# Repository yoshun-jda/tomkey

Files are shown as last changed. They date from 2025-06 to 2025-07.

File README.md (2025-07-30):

## description
- このキーボードは無線分割式 40% 19mm トラックボール内蔵のキーボードになります。
  tomkey keyboard

## ビルドガイド
- https://github.com/pukuhei/tomkey/blob/main/build_guide/build_guide.md
## スペック
- ファームウェア
  - ZMK を使用しています
  - ZMKStudio に対応しております
- ハードウェア
  - 43 キー
  - choc v1/v2、lofree 系列のスイッチが使用可能
  - 左手側が master,右手側が slave になります
  - 左手側に OLED 内蔵
  - トラックボールはケースごとマグネットで張り付いているので、脱着可能です
  - バッテリー対応 2 つ必要です
    - 横 25mm,縦 35mm,厚さ 5mm 以内のものを使用してください
    - 製作者はこちらを使用しています(https://amzn.asia/d/ebvtzoP)。250mAh で大体 1 週間は持ちます(1 日 5 時間使用くらい)
    - リチウムイオンバッテリーは十分注意して取り扱ってください(https://www.baj.or.jp/battery/safety/safety16.html)
    - 市販のバッテリーの極性が個体によって異なる例が確認されておりますので、極性には気をつけてご利用ください。tomkey では赤色を+極として作成しております

## 電源および充電について
※ご自身で購入したバッテリーによっては極性が逆になっている可能性がありますので、十分にご確認の上で接続をお願いいたします！(表記と端子が逆の事例もありました)
- スイッチを ON にしている状態で USB に接続することで充電されます。充電しながらの使用も可能です
- スイッチが OFF の状態で USB を接続すると USB からの給電で使用できますが、OFF の状態ではバッテリーに充電はされません
  - 安全上意図的にバッテリー ON 状態でないと充電されない仕様になっております
- バッテリー残量に関しては oled 上に表示されるようになっております
  - 上側が左手のバッテリー残量
  - 下側が右手のバッテリー残量

## oled の切り替えについて

- デフォルトでは us 配列の mac に適した配置になっております
- また oled も mac に併せてありますので、windows の方は以下の設定を n に指定することで表示が切り替わります
- config/boards/shields/tomkey/tomkey_L.conf
- `CONFIG_ZMK_DONGLE_DISPLAY_MAC_MODIFIERS=n`にする

## キーマップについて

- ZMKstudio にて確認・編集を行なってください

  - https://zmk.studio/

- ZMK keymap-editor も使用できます
  - マクロ設定などを使いたい場合はこちらを使うとべんりです
  - https://nickcoutsos.github.io/keymap-editor
  - ご使用の時は本リポジトリをフォークしてお使いください
    - ※フォークしてマクロ等にパスワードなどを設定する際はリポジトリが public になってしまい情報漏洩につながりますのでご注意ください

### レイヤーマップ

- レイヤー 0 がデフォルトです
- レイヤー 1 がオートマウスレイヤーです
  - トラックボール操作中に切り替わるレイヤーです(400ms でレイヤー０に切り替わります)
- レイヤー 2 がスクロールレイヤーです
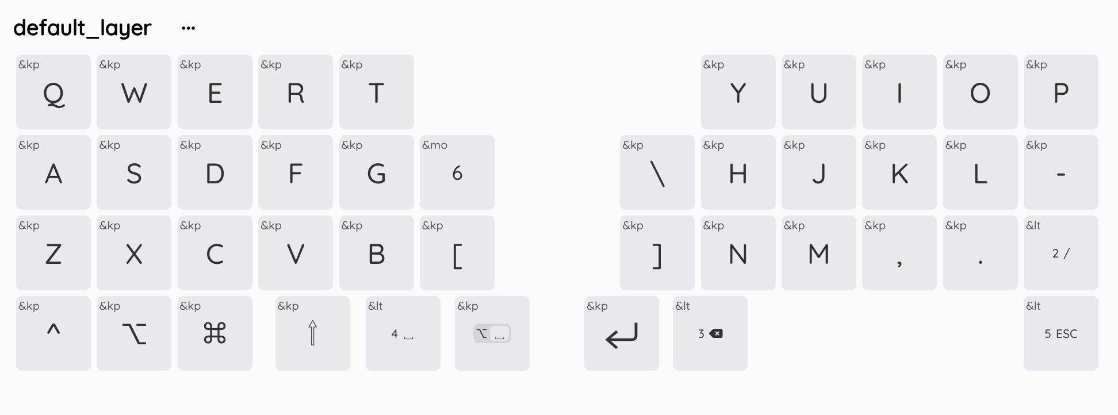
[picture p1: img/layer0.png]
tomkey layer0
  
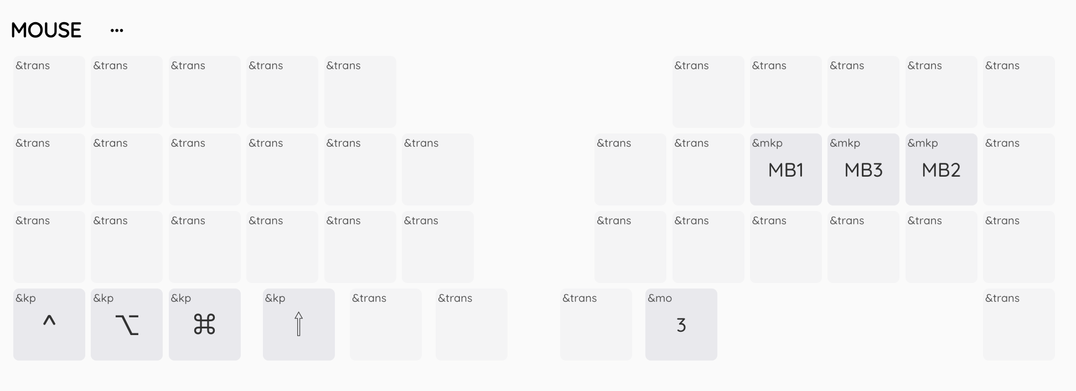
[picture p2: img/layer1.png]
tomkey layer1
  
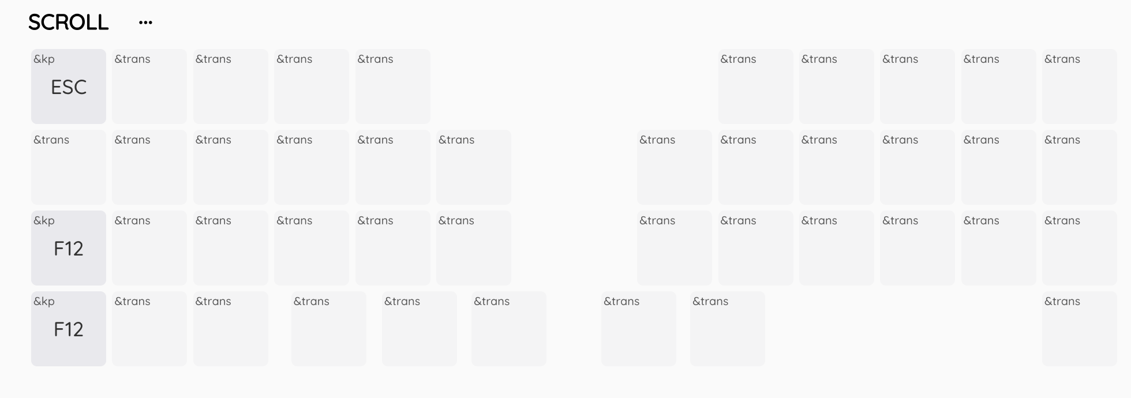
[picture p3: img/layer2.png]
tomkey layer2
  
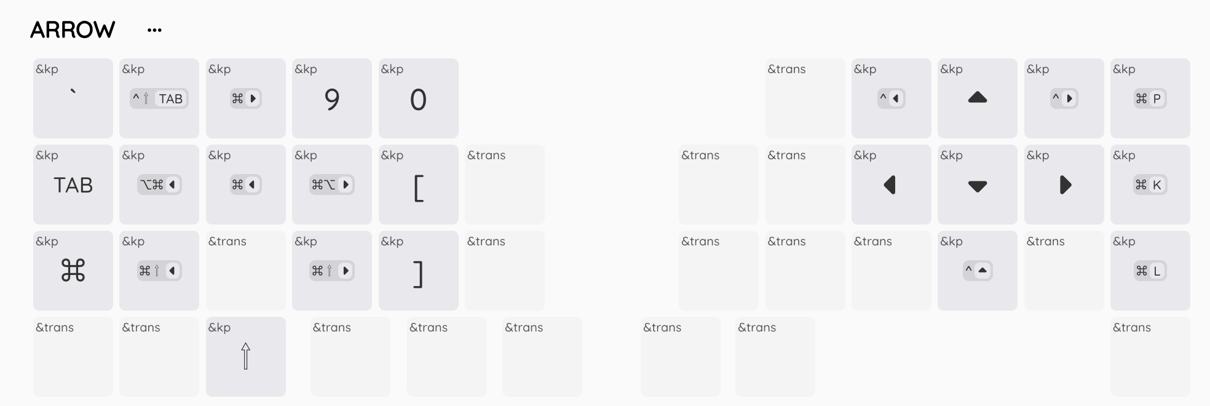
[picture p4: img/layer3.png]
tomkey layer3
  
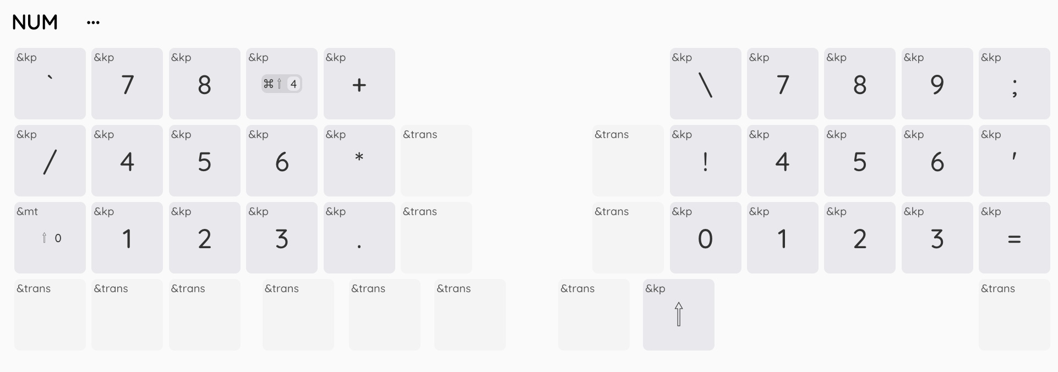
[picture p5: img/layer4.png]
tomkey layer4
  
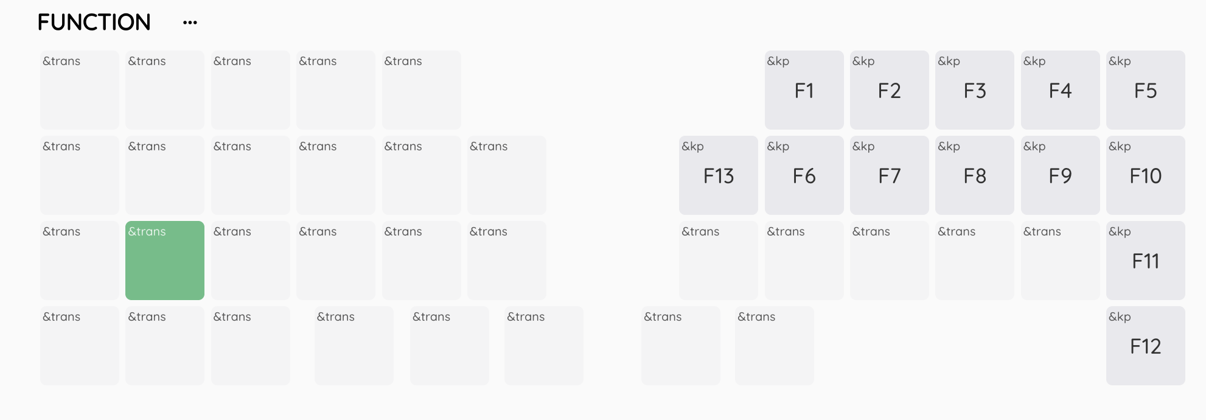
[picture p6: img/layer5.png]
tomkey layer5
  
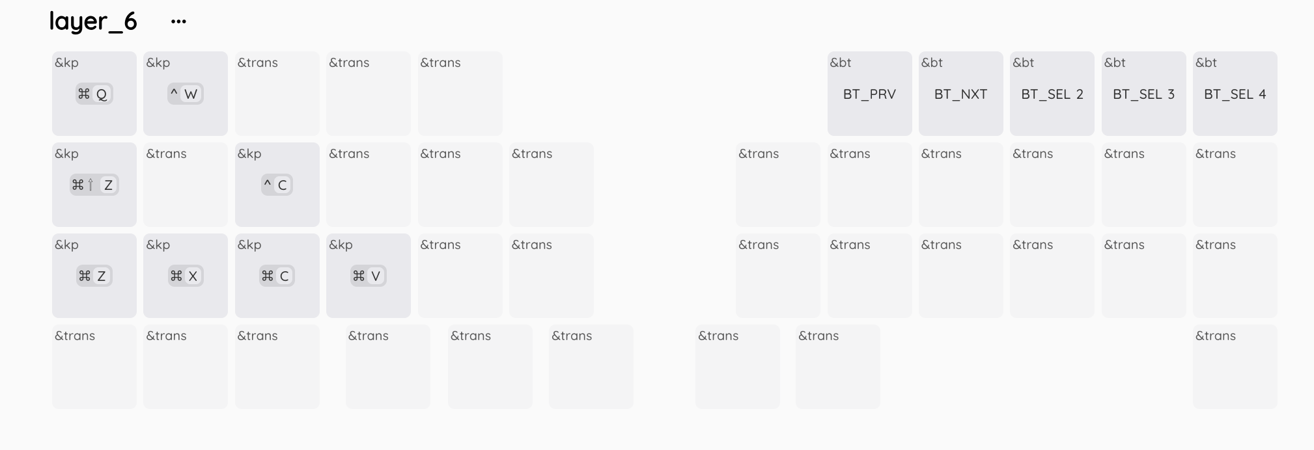
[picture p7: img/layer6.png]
tomkey layer6
  

## その他

不明な点がある場合は下記アカウントにご連絡ください
https://x.com/tomcat09131

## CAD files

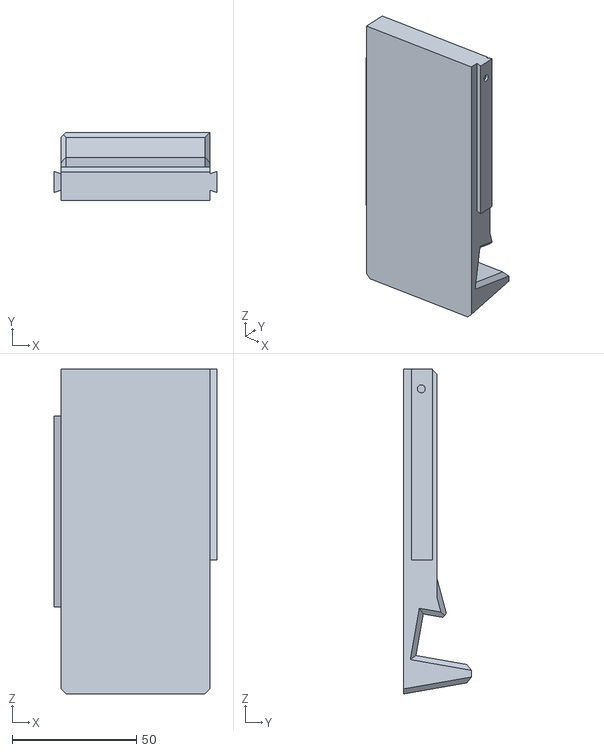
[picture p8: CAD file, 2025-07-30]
model/linker-stand.stl
65.6 x 27.5 x 131.0

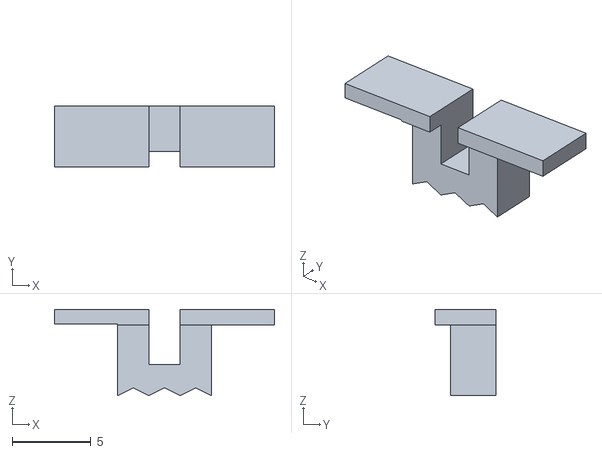
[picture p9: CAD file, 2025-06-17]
model/tomkey-r-sw.stl
14.0 x 3.90 x 5.50

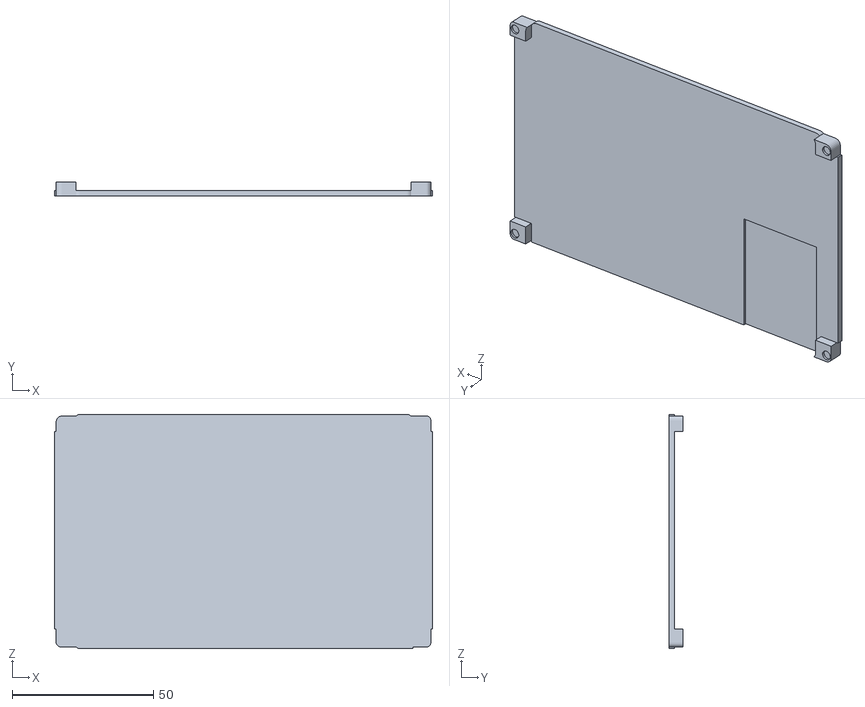
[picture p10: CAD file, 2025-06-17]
model/tomkey-r-bottom.stl
134.0 x 5.00 x 83.0

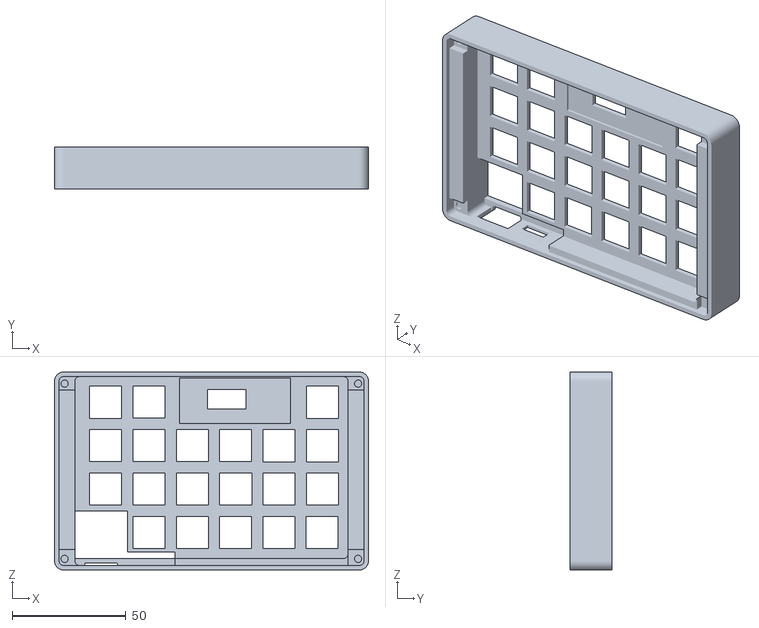
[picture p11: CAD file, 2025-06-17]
model/tomkey-r-body.stl
138.0 x 18.5 x 87.0

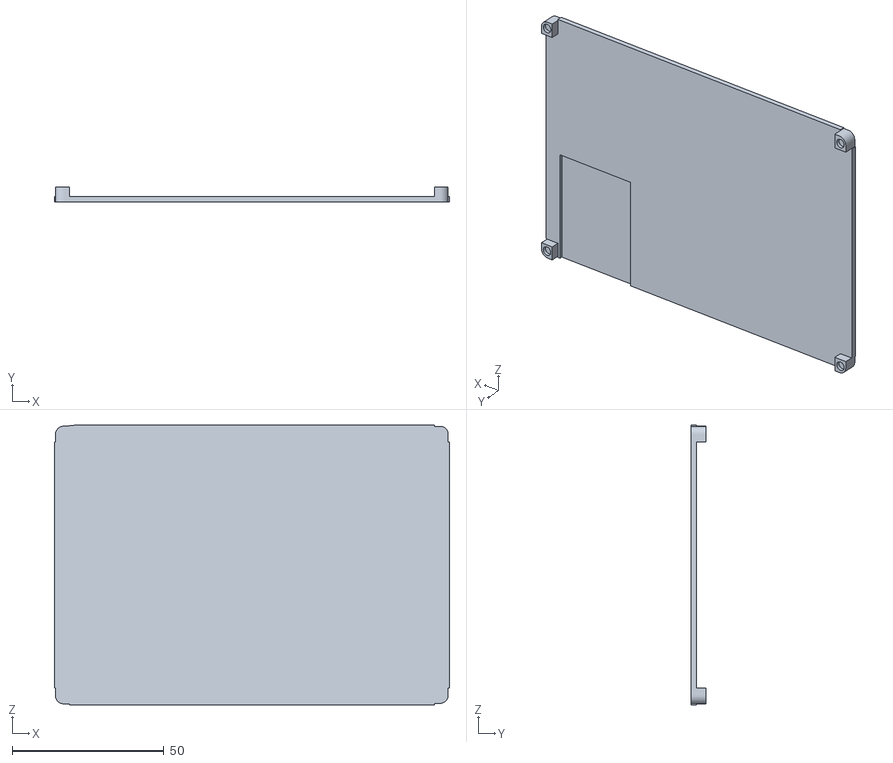
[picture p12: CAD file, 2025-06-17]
model/tomkey-l-bottom.stl
130.0 x 4.90 x 92.0

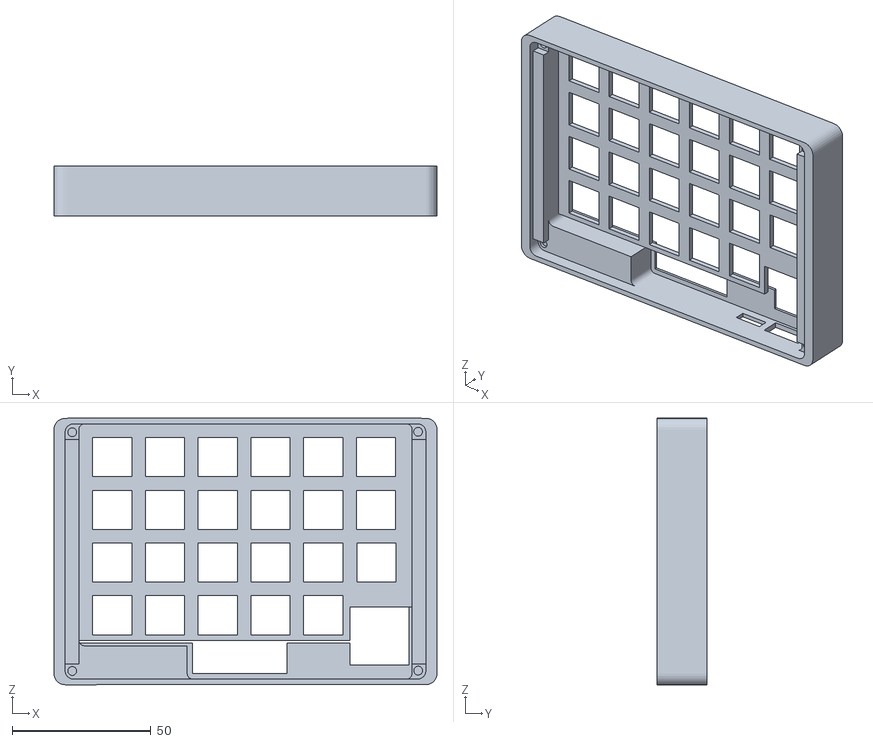
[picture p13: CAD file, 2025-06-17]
model/tomkey-l-body.stl
138.0 x 18.0 x 96.0

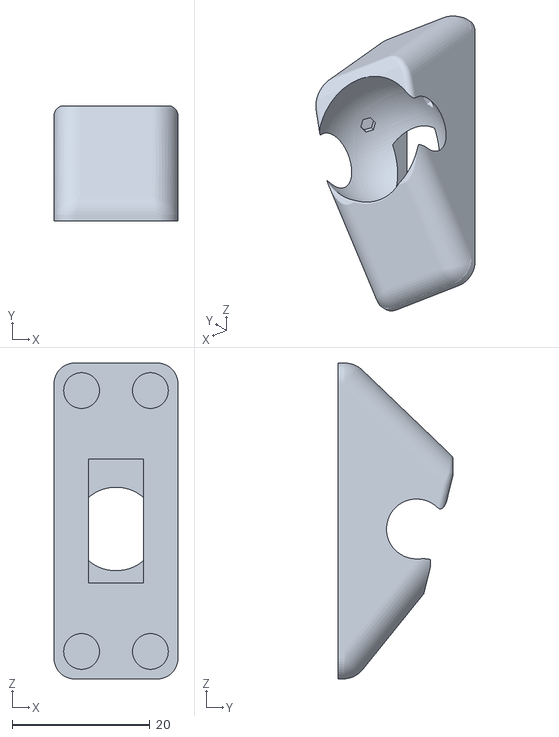
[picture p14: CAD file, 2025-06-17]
model/trabo.stl
18.0 x 16.8 x 45.9

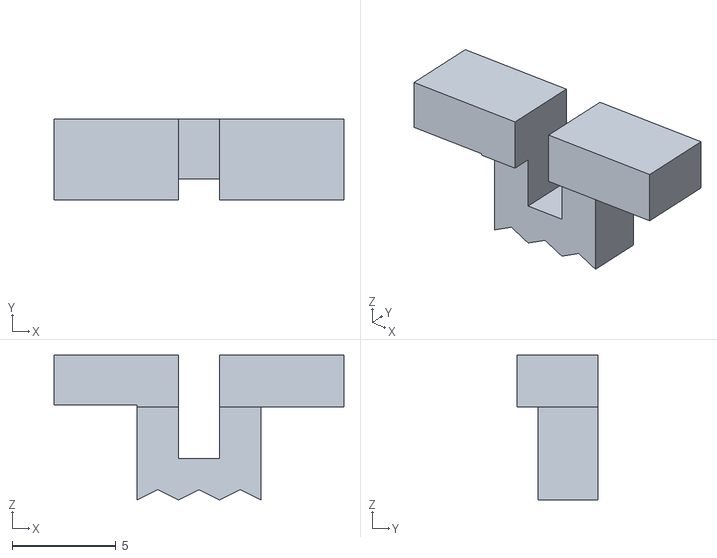
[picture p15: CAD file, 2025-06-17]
model/tomkey-l-sw.stl
14.0 x 3.90 x 7.00

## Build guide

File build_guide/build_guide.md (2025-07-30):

## マイコンカバーについて

- マイコンカバーは選択式のため、固定はしておりませんためそのままの状態だと外れることがあります
- 使用する場合は裏面に小さく両面テープなどをつけて固定しておつかください

## トラックボールセンサーについて

- トラックボールセンサーのレンズユニットが使っていると振動や摩耗などで浮いてくる場合があります。
- ウキがあるとトラックボールが正常に認識できませんので上から軽く押して止め直してください。必要に応じて接着剤などで固定をお願いします
  - 組み立て時点でウキがあるものは製作者側で接着固定している場合があります

## 電源スイッチカバーの取り付け

- 一応スイッチには上下で形状が異なります。通常の画像の向き(下側が平らで、上側が出っ張り)で取り付けます。もしスイッチが緩くてアソビが強い場合は上下逆にして取り付けてください
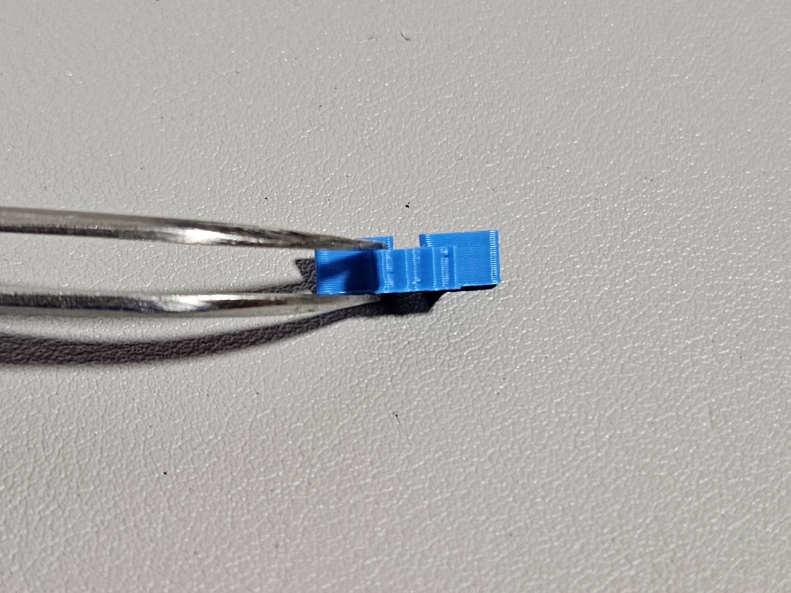
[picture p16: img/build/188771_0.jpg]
sw01
- 
- またスイッチは厚みがある方が左手側、薄い方が右手側のスイッチになります

## キースイッチの取り付け

- キースイッチを取り付ける際は、ケースを持ちながら基盤を後ろから支えて押し込んで挿入します
- 差し込みが甘いとキー入力ができませんので、しっかりと全部奥まで差し込まれていることを確認の上でご使用ください
- 差し込んでいるのにキースイッチが反応しない場合は、 スイッチのピンを曲げてしまっている可能性があるので取り付け直してください
- 最初に四隅から取り付けると安定して取り付けやすいです
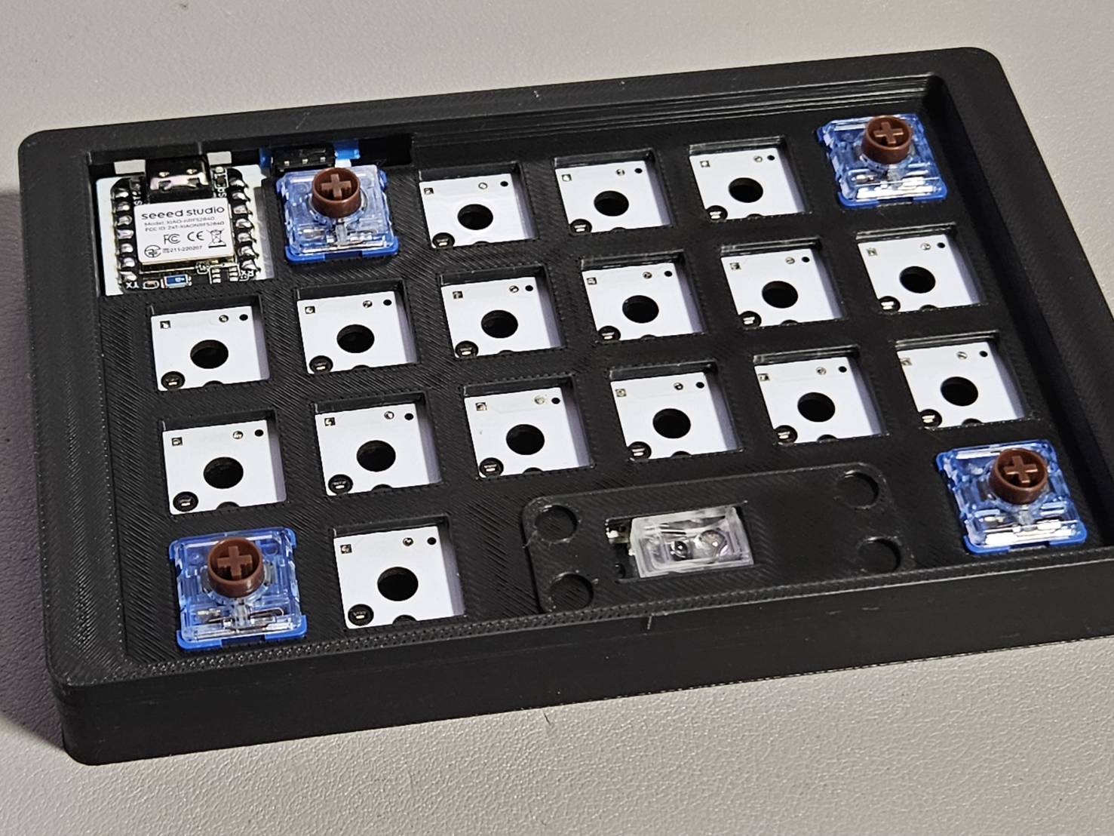
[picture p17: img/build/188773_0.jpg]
ksw01
- 
- 外す時はケース裏側から、スイッチのセンターを押し出すと簡単に外れます。硬い場合はピンセット裏側など固いもので押し込むとやりやすいです
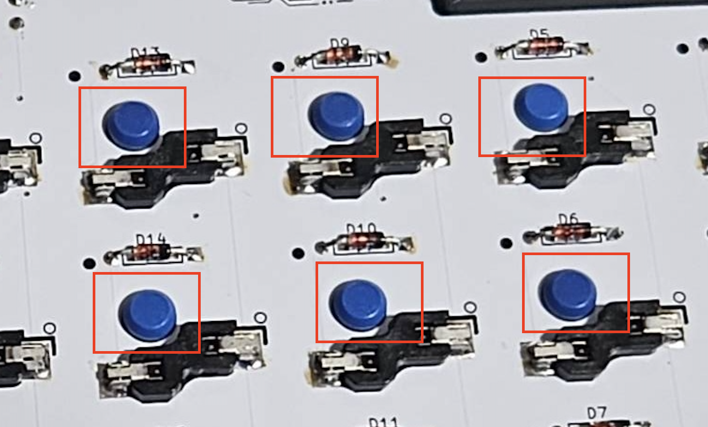
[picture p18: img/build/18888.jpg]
ksw02
- 

## バッテリーの接続

- マイコン部分の裏側にあらかじめ JST プラグ 1.25mm のメス端子を接続してありますので、裏面カバーを外してここにバッテリーを接続します
- 購入されるバッテリーによっては、+極と-極が逆に接続されている可能性があります。その状態で本体と接続しますとマイコンの破壊、バッテリーの発火の原因となりますので事前に確認を行なった上で取り付けをお願い致します
- tomkey では+極を赤色、GND を黒色で配線しております
- 基本的にご購入されたバッテリーは動作確認済品をおつけしております
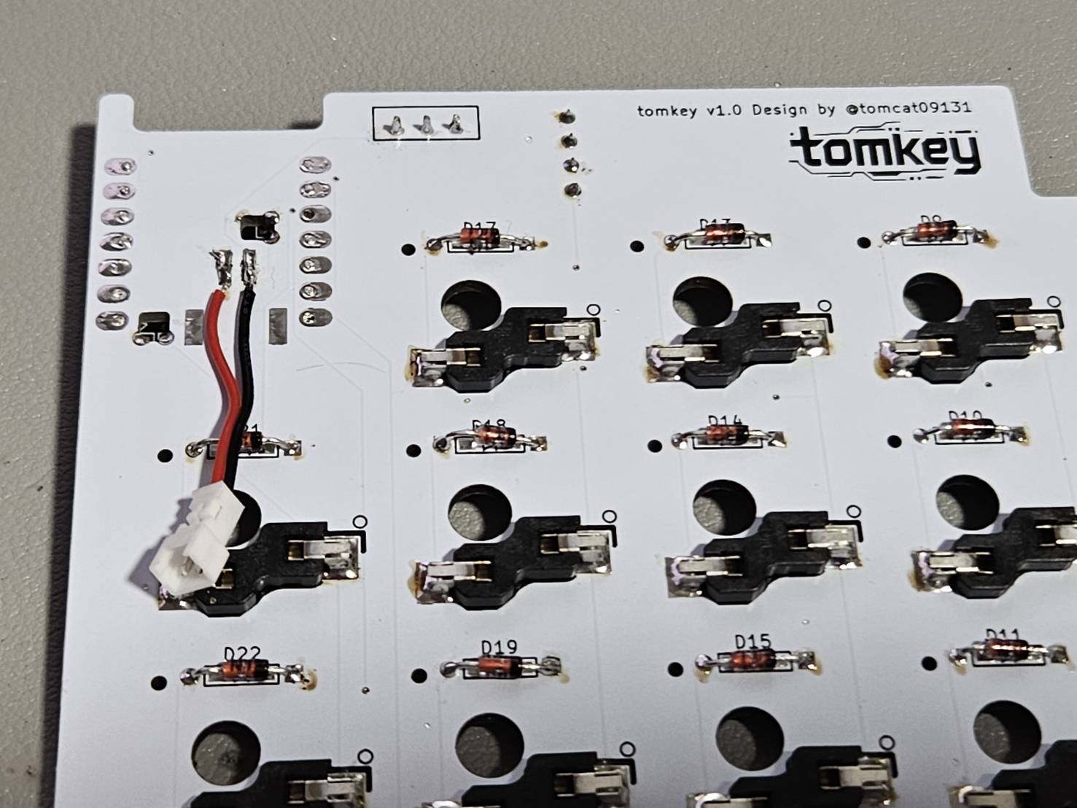
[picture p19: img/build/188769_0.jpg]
bat01
  - 
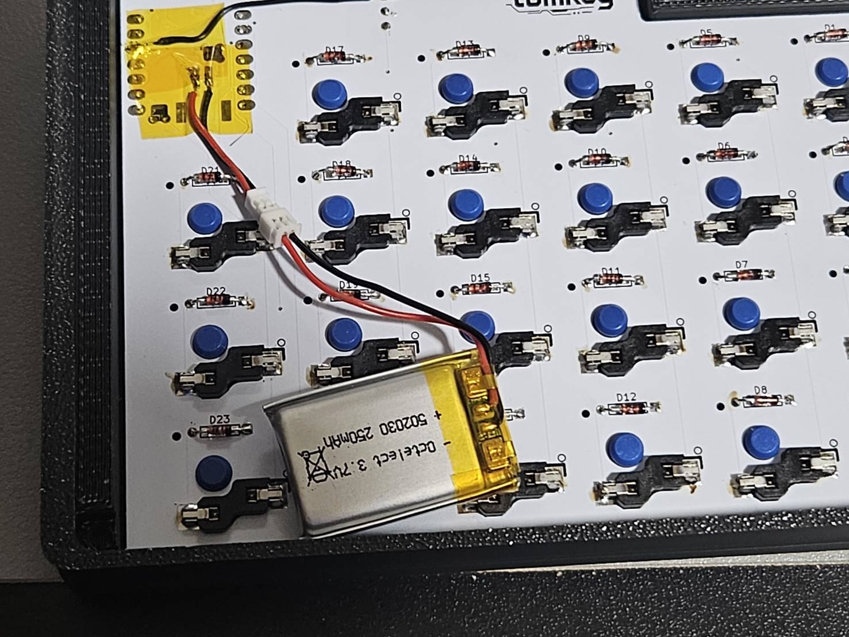
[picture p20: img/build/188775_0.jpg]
bat02
  - 

## ファームウェアの焼き方

- マイコンの左上のリセットスイッチを細い棒などで 2 回連続押すと、PC で外部ストレージとして認識されます
- 完全組み立て品の場合は、リセットスイッチカバーの突起が出ているのでそれを 2 回押してください
  - maikon01
- 本リポジトリをフォークしてもらって、keymapEditor やコードエディタで編集しフォークしたリポジトリに push 後、GithubAction が自動で走るので完了後にビルドされたファームを左右のマイコンにそれぞれドラッグ＆ドロップでコピーしてください
  - zip ファイルの中身はこちらになります
  - マイコン初期化:settings_reset-seeeduino_xiao_ble-zmk.uf2
  - 左:tomkey_L dongle_display-seeeduino_xiao_ble-zmk.uf2
  - 右:tomkey_R-seeeduino_xiao_ble-zmk.uf2

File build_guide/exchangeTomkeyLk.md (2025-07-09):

# tomkey → tomkeyLk への交換キットの交換手順

## 付属品

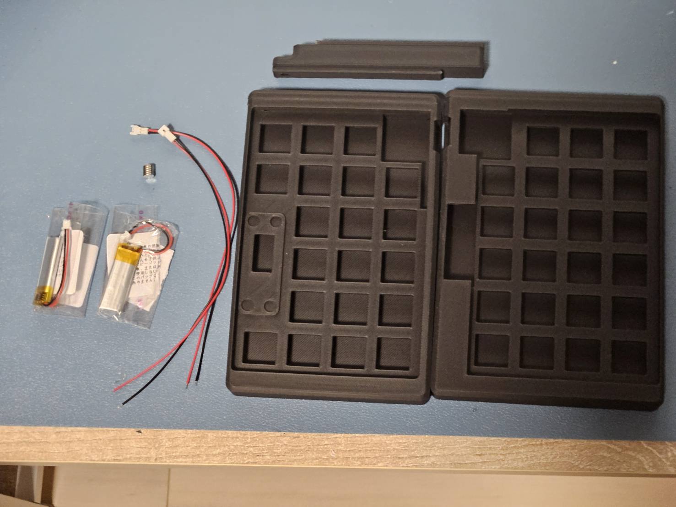
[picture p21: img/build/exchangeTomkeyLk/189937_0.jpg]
eLk1


- tomkeyLk ケース左右一式
- 左右接続のための linker
- PH1.25 ケーブル メス x2
- 100mAh バッテリー x2
- 5mm マグネット 4 個 + 1 個（予備）

## 交換に必要な備品

- ハンダゴテ
- ハンダ
- 絶縁テープ（一応マスキングテープでも OK）
- 瞬間接着剤
- ピンセット（ハンダ作業時）

## 交換手順

予め、tomkey の方のスイッチやバッテリーなどを全て外し、ケースから外しておいた状態にしておいてください。

### PH1.25 ケーブルの取り付け

先に基板に長めの PH1.25 ケーブルを取り付けます
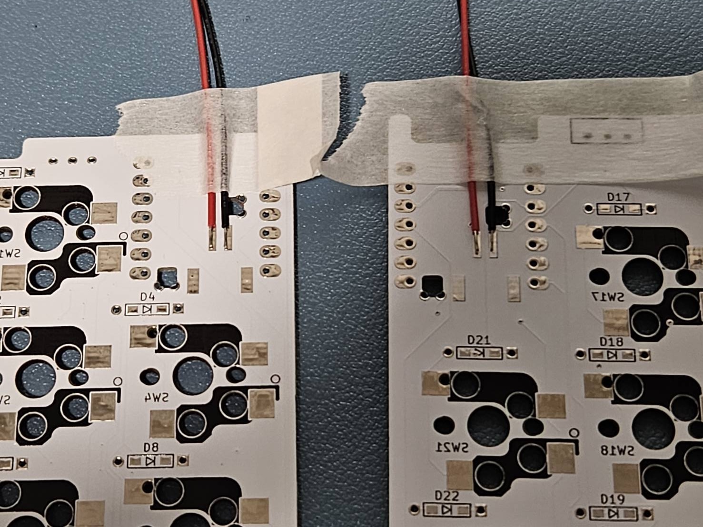
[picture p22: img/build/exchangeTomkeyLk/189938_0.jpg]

最初についているケーブルはハンダで温めて外します。素手で触ると危険なのでピンセットを使ってください。
取り外したら、新しい PH1.25 ケーブルを写真のようにマスキングで固定しながら取り付けます。
配線に色や向きに関しては写真を参考に注意して取り付けてください。

### ケースの取り付け

例として先に右側を説明します。

まず、tomkeyLk のケースから bottom ケースを外します
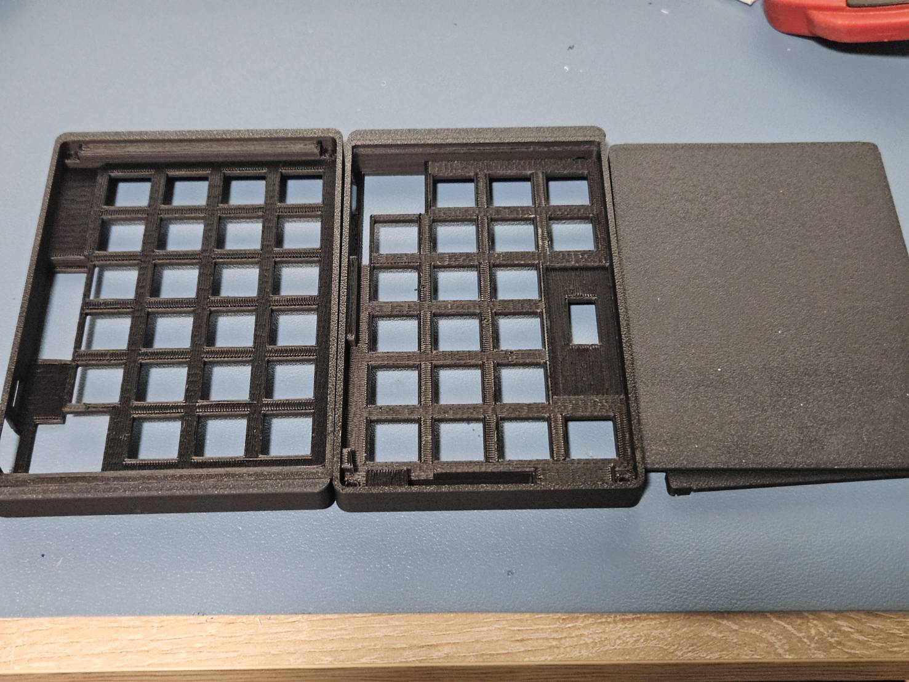
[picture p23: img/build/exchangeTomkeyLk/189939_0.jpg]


基板をケースに入れる前にスイッチカバーを取り付けます。スイッチカバーは既存のものを使用してください
eLk2
スイッチカバーは向きがあり、全体が平らになっている方を底面方向に向けて取り付けます。（左右で微妙に厚さが異なるので注意ください）

取り付けたら基板を後ろから押さえながらキースイッチを取り付けてください。この時点で全てキースイッチを取り付けてしまっても OK です。
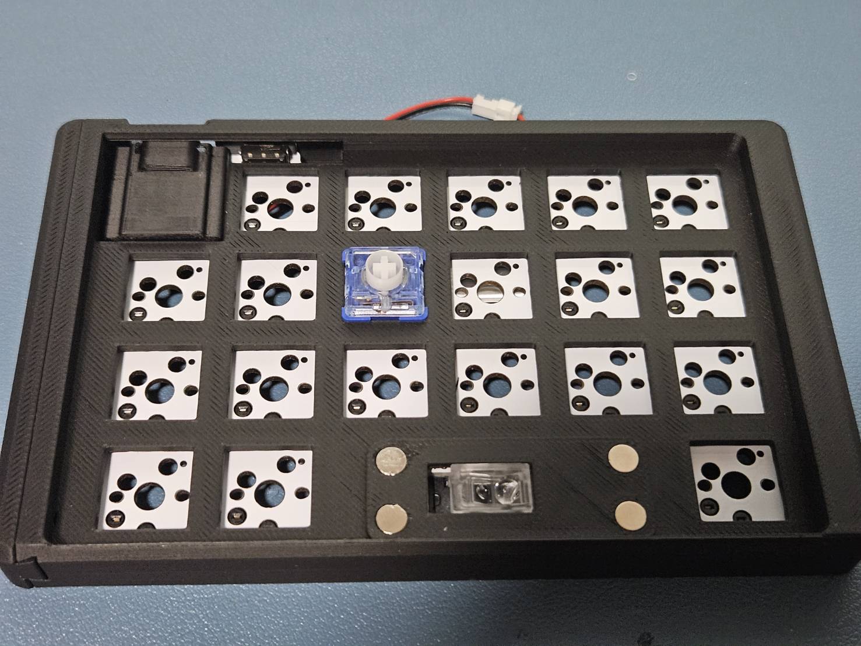
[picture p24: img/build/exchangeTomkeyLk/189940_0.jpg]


同様の要領で左側も行なっていきます。

### 配線の取り回し

ケースとキースイッチを取り付け終わったら、バッテリーを取り付けて配線を取り回します。
決められた位置にバッテリーを設置しないと裏蓋が閉まらないため写真を参考に作業を行ってください。
配線に関してはテープで止めても止めなくてもケースに収まりますが、PH1.25 同士の接続部のみは決めれれたスペースに収めてください

右手側
一番左の溝にバッテリー用のスペースがあるのでそこに格納します。PH1.25 同士の接続部は上側にスペースを設けているのでそこに設置します。
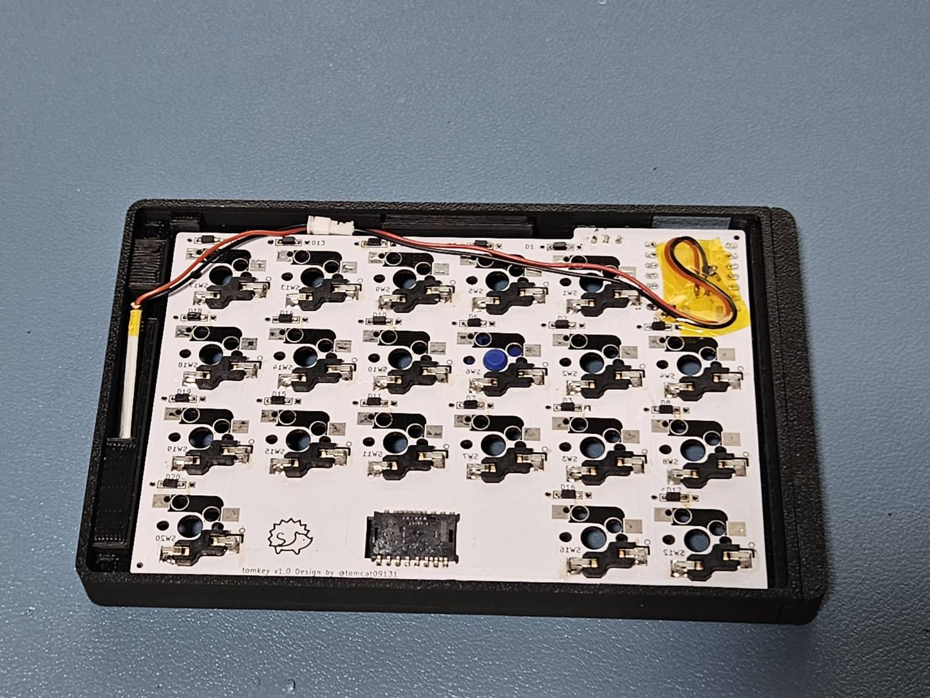
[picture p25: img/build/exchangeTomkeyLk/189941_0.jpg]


左手側
右上のスペースに格納します。PH1.25 同士の接続部もそこにまとめて格納するので、予めテープでバッテリーと端子部分をテープで固定すると楽です。
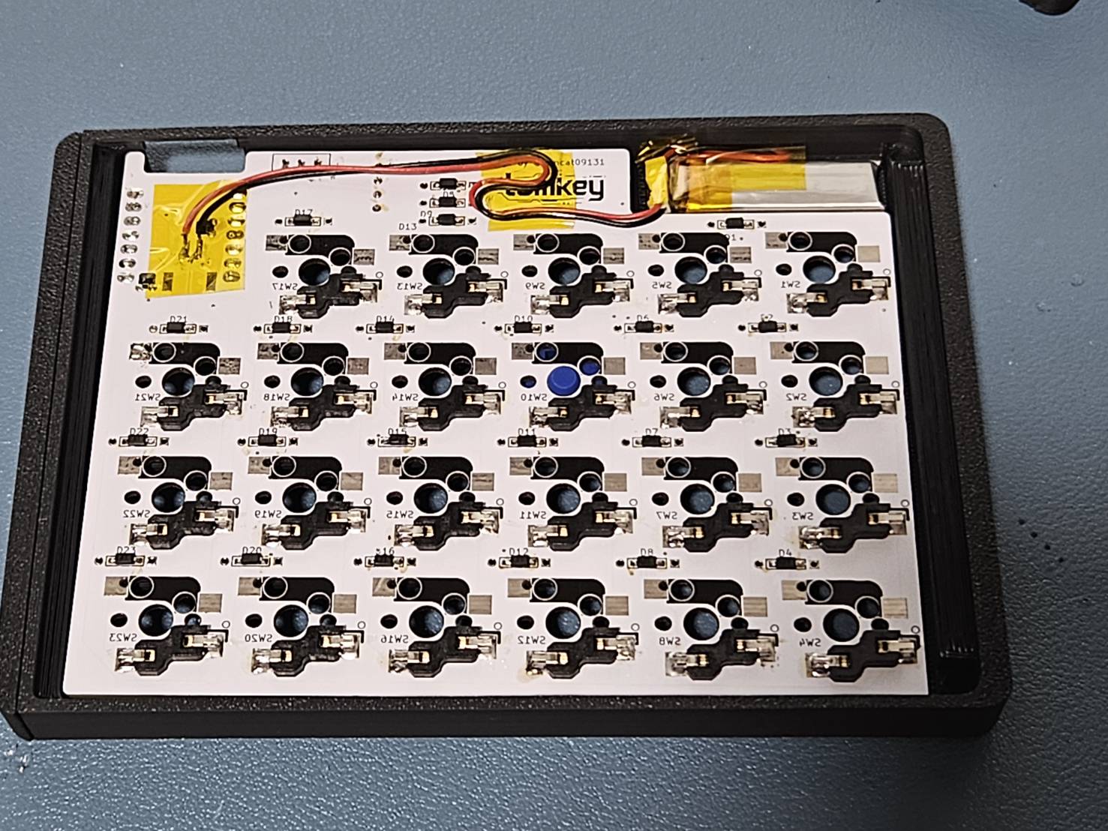
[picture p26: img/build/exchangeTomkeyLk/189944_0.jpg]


### トラックボールケース用マグネットの取り付け

まずは、トラックボールケースの底面にマグネットを４つ取り付けます。この時点ではまだ接着剤で固定しないでください

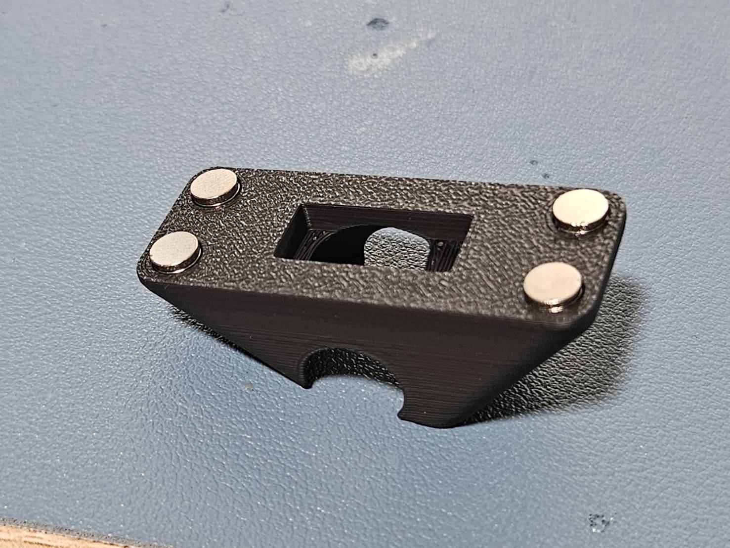
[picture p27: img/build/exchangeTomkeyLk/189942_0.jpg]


右手の４つの穴に瞬間接着剤を少量流して、トラックボールケースを４つの磁石を押し込むように差し込みます。
瞬間接着剤の量が多いと、穴から溢れてトラックボールケースが固定されてしまうので気をつけてください。
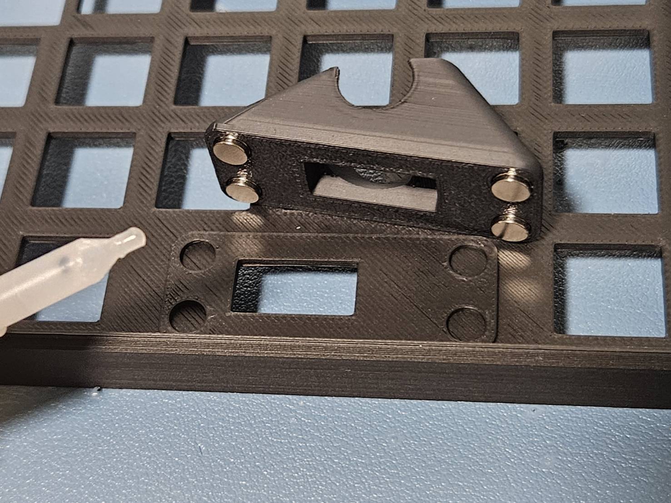
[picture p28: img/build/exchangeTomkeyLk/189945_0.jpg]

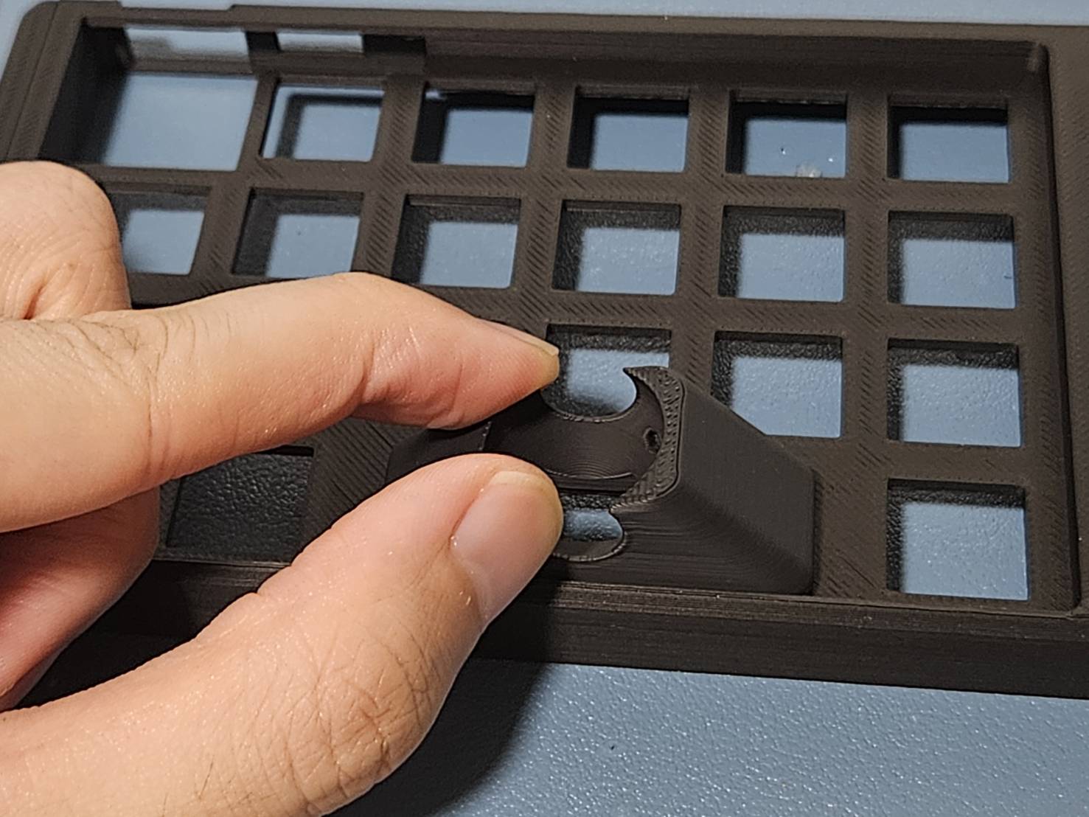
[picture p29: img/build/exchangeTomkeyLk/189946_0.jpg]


30 秒ほど押さえたらある程度接着できているはずですので、横にずらすようにしながらトラックボールケースを取り外します。
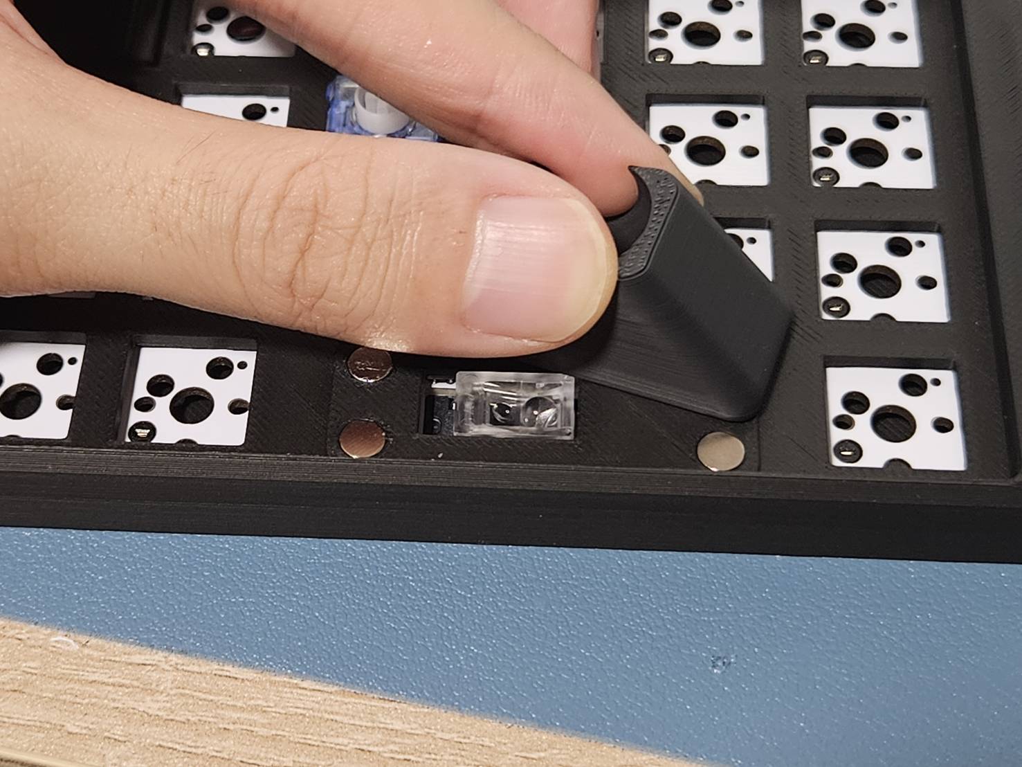
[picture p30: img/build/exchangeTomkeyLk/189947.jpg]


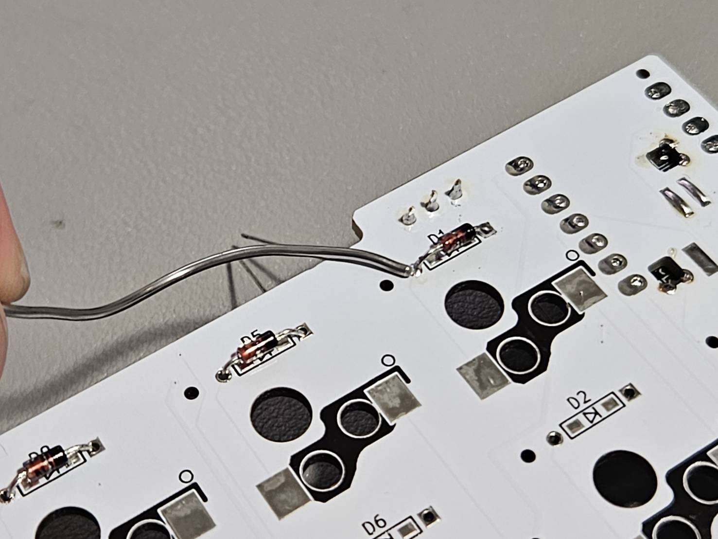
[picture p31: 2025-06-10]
img/build/188756_0.jpg

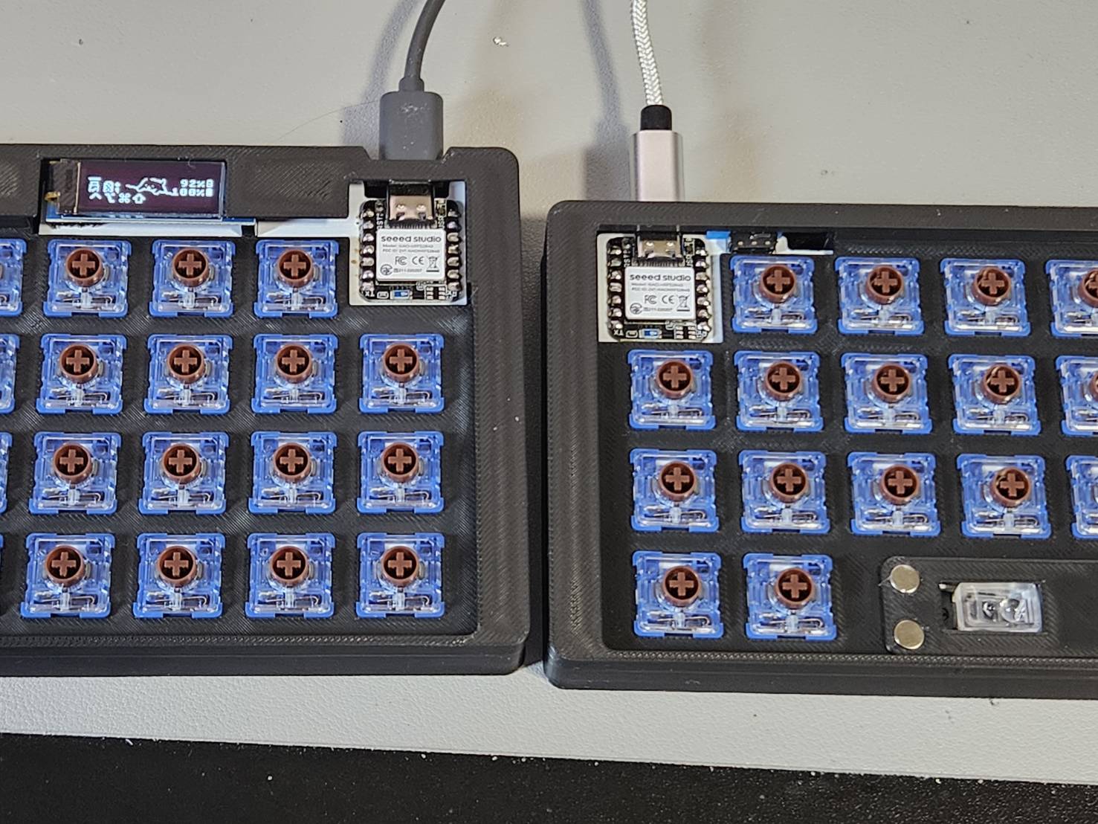
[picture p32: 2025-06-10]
img/build/188776_0.jpg

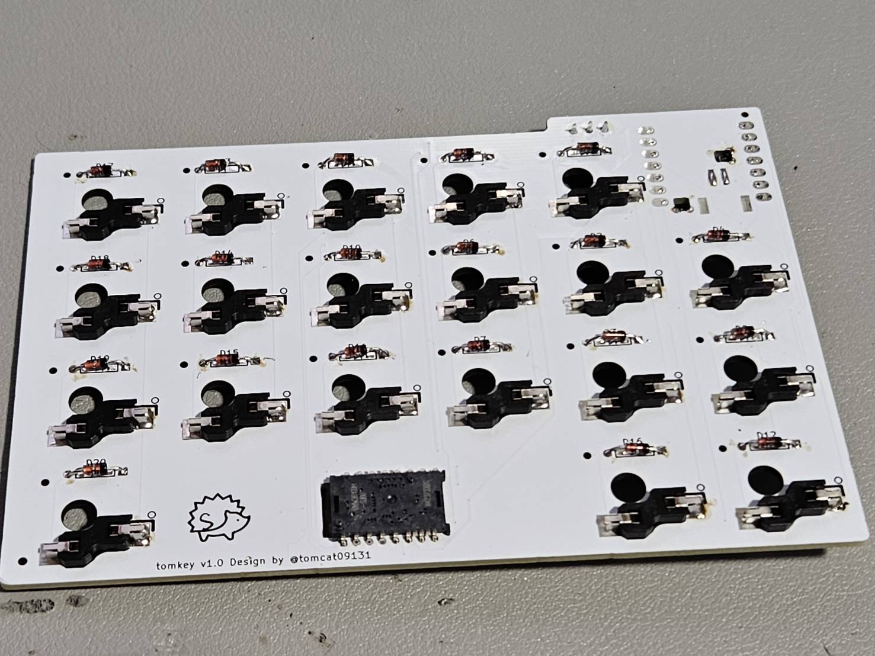
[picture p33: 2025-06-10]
img/build/188761_0.jpg

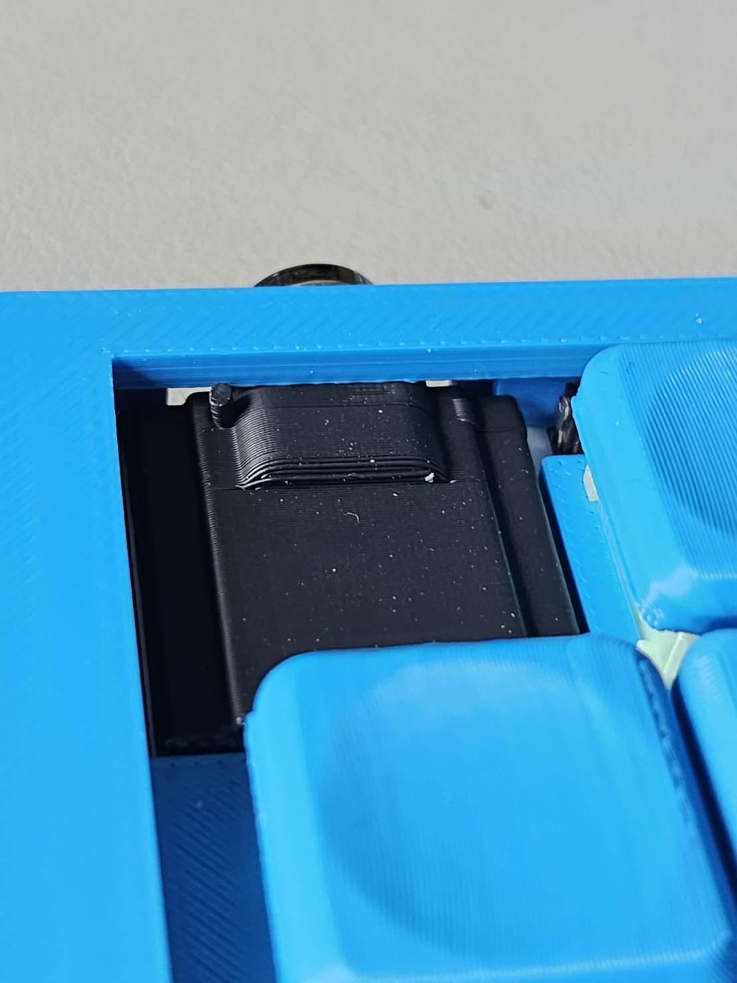
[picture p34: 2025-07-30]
img/build/190841.jpg

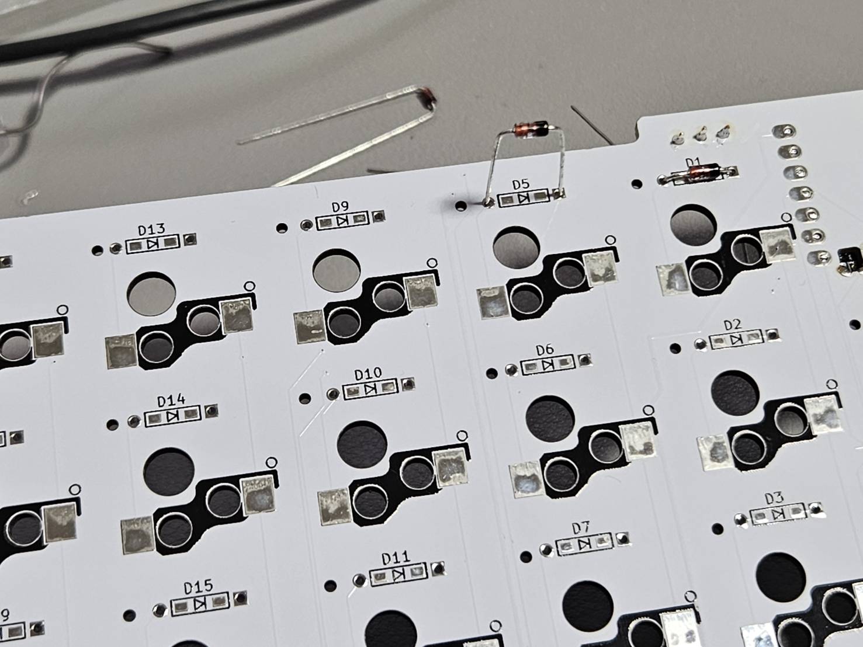
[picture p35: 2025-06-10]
img/build/188754_0.jpg

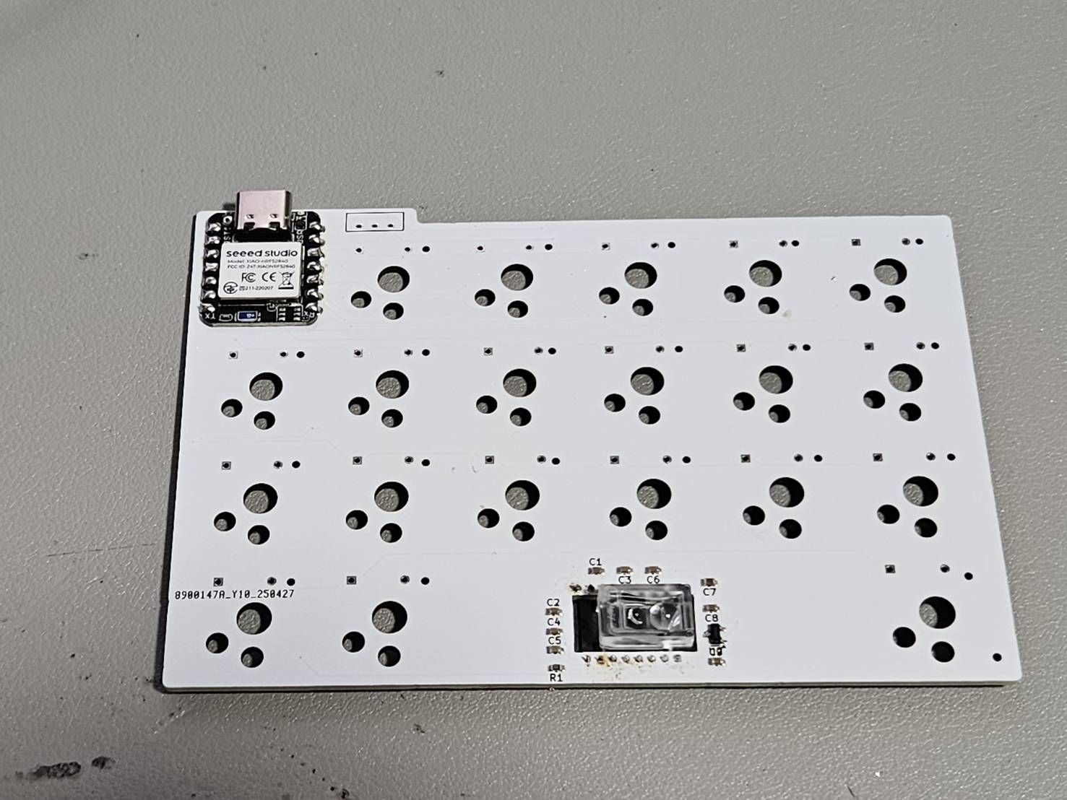
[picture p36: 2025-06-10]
img/build/188751_0.jpg

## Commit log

2025-05-31 img追加
2025-05-31 レイヤーの説明追加
2025-06-10 buildguideの写真追加
2025-06-10 ビルドガイドのリンク追加
2025-06-12 oledをwindowsmodeに
2025-06-13 バッテリーの注意喚起をtopに表示
2025-06-17 3dmodel追加
    [tomkey-l-body.stl, tomkey-l-bottom.stl, tomkey-l-sw.stl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]
2025-06-17 cpi設定追加
2025-06-20 buildguide更新
2025-07-09 tomkeyLk交換キットのビルドガイドを更新
2025-07-29 cpi設定がオーバーライドされていたので削除
2025-07-30 画像追加
2025-08-14 Update tomkey_R.overlay
    cpiを600に
